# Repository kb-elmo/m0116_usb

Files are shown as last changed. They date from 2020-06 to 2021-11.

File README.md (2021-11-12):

# m0116_usb
[][cc-by-nc-sa]<a href="https://ko-fi.com/kb_elmo">kofibadge</a>

## This project is completed and will not get updated anymore.

### QMK compatible drop-in replacement PCB for the Apple M0116
The PCB is built entirely with THT parts to keep a somewhat "vintage" look to it and it uses the fullsize 40-pin DIP package ATmega32A.
The controller is placed in the exact same location as the one on the original PCB meaning that it can be accessed through the plate cutout under the spacebar.




### Partslist
 |Count|Part|
 |-|-|
 |1|ATmega32A 40 pin DIP (32L works too)|
 |1|40 pin DIP socket (optional but highly recommended)|
 |1|2x3 pin header 2.54mm (for ISP flashing)|
 |1|JST PH 2mm 4pin connector + cable|
 |1|mini usb port|
 |1|500 mA polyfuse|
 |2|6mm momentary push buttons|
 |1|16 MHz quarz crystal|
 |1|4.7 uF electrolytic capacitor|
 |2|100 nF ceramic disk capacitor|
 |2|22 pF ceramic disk capacitor|
 |1|10 kΩ resistor|
 |2|68 Ω resistor|
 |1|1.5 kΩ resistor|
 |2|3.6 V zener diode (DO-35 BZX55C3V6)|
 |81|universal switching diode (DO-35 1N4148)|

#### Some pictures of the first finished PCB
(https://i.imgur.com/0l0W3oY.jpg) (https://i.imgur.com/iAKeK4c.jpg)
(https://i.imgur.com/Zk1t3iO.jpg) (https://i.imgur.com/qjwVC6q.jpg)
(https://i.imgur.com/mmxlIqL.jpg) (https://i.imgur.com/rhK3iEW.jpg)

This work is licensed under a
[Creative Commons Attribution-NonCommercial-ShareAlike 4.0 International License][cc-by-nc-sa].

[][cc-by-nc-sa]

[cc-by-nc-sa]: http://creativecommons.org/licenses/by-nc-sa/4.0/
[cc-by-nc-sa-image]: https://licensebuttons.net/l/by-nc-sa/4.0/88x31.png
[cc-by-nc-sa-shield]: https://img.shields.io/badge/License-CC%20BY--NC--SA%204.0-lightgrey.svg

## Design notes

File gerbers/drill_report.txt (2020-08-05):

Drill report for m0116_usb.kicad_pcb
Created on Wed Aug  5 12:54:41 2020

Copper Layer Stackup:
    =============================================================
    L1 :  F.Cu                      front
    L2 :  B.Cu                      back

Drill file 'm0116_usb.drl' contains
    plated through holes:
    =============================================================
    T1  0.40mm  0.016"  (4 holes)
    T2  0.70mm  0.028"  (7 holes)  (with 7 slots)
    T3  0.75mm  0.030"  (4 holes)
    T4  0.80mm  0.031"  (230 holes)
    T5  1.00mm  0.039"  (8 holes)
    T6  1.10mm  0.043"  (8 holes)
    T7  1.47mm  0.058"  (162 holes)

    Total plated holes count 423

Not plated through holes are merged with plated holes
    unplated through holes:
    =============================================================

    Total unplated holes count 0

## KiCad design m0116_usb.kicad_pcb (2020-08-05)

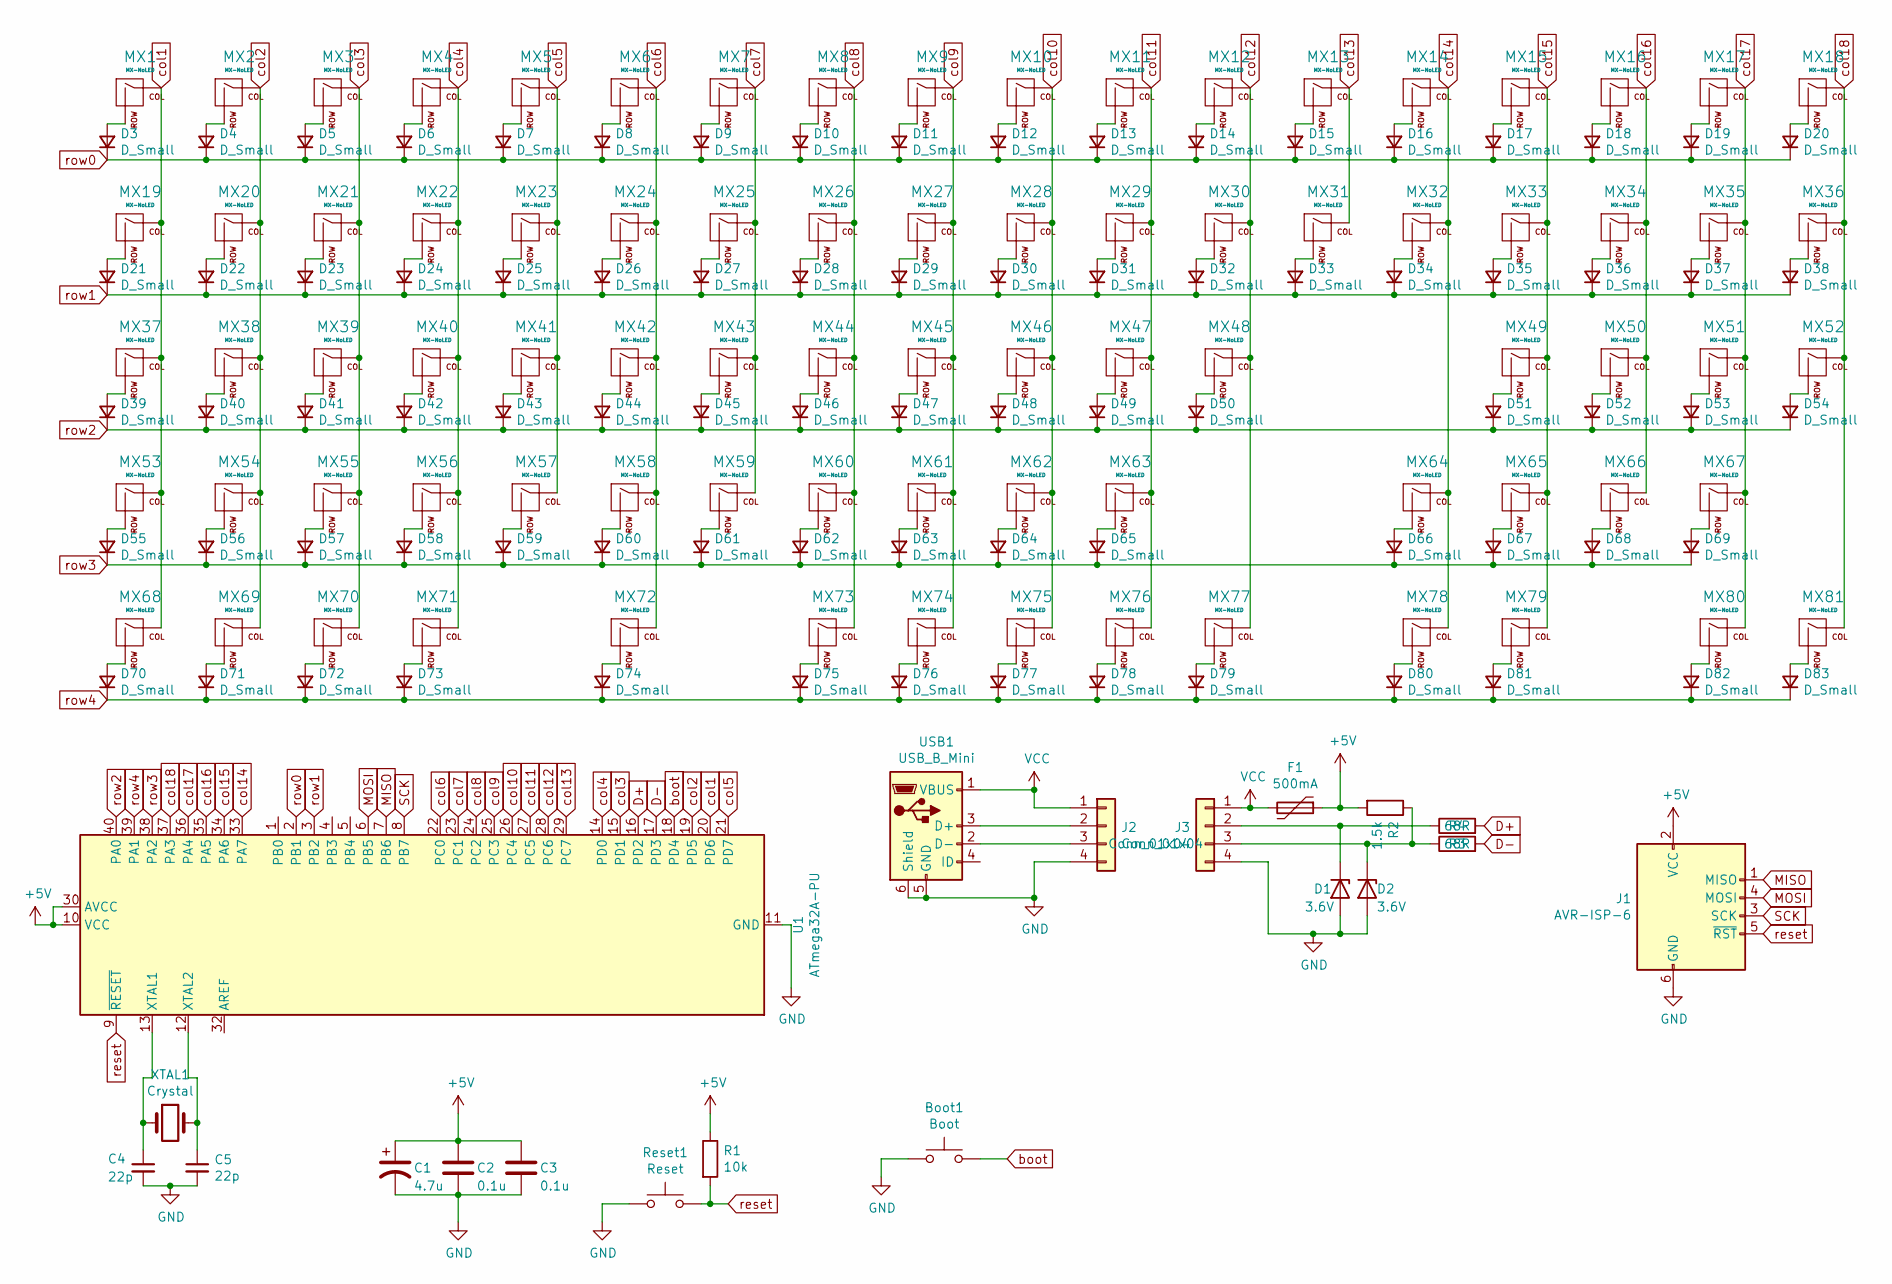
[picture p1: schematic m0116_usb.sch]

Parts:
Boot1: Boot; SW_PUSH_6mm
C1: 4.7u; CP_Radial_D5.0mm_P2.50mm
C2, C3: 0.1u; C_Disc_D3.0mm_W2.0mm_P2.50mm
C4, C5: 22p; C_Disc_D6.0mm_W2.5mm_P5.00mm
D1, D2: 3.6V; D_DO-35_SOD27_P7.62mm_Horizontal
D3, D4, D5, D6, D7, D8, D9, D10, D11, D12, D13, D14, D15, D16, D17, D18, D19, D20, D21, D22, D23, D24, D25, D26, D27, D28, D29, D30, D31, D32, D33, D34, D35, D36, D37, D38, D39, D40, D41, D42, D43, D44, D45, D46, D47, D48, D49, D50, D51, D52, D53, D54, D55, D56, D57, D58, D59, D60, D61, D62, D63, D64, D65, D66, D67, D68, D69, D70, D71, D72, D73, D74, D75, D76, D77, D78, D79, D80, D81, D82, D83: D_Small; D_DO-35_SOD27_P7.62mm_Horizontal
F1: 500mA; Fuse_Littelfuse_395Series
J1: AVR-ISP-6; PinHeader_2x03_P2.54mm_Horizontal
J2: Conn_01x04; PinHeader_1x04_P2.00mm_Vertical
J3: Conn_01x04; JST_PH_S4B-PH-K_1x04_P2.00mm_Horizontal
MX1, MX2, MX3, MX4, MX5, MX6, MX7, MX8, MX9, MX10, MX11, MX12, MX13, MX14, MX15, MX16, MX17, MX18, MX19, MX20, MX21, MX22, MX23, MX24, MX25, MX26, MX27, MX28, MX29, MX30, MX31, MX32, MX33, MX34, MX35, MX36, MX37, MX38, MX39, MX40, MX41, MX42, MX43, MX44, MX45, MX46, MX47, MX48, MX49, MX50, MX51, MX52, MX53, MX54, MX55, MX56, MX57, MX58, MX59, MX60, MX61, MX62, MX63, MX64, MX65, MX66, MX67, MX68, MX69, MX70, MX71, MX72, MX73, MX74, MX75, MX76, MX77, MX78, MX79, MX80, MX81: MX-NoLED; ALPS-1U
R1: 10k; R_Axial_DIN0207_L6.3mm_D2.5mm_P10.16mm_Horizontal
R2: 1.5k; R_Axial_DIN0207_L6.3mm_D2.5mm_P10.16mm_Horizontal
R3, R4: 68R; R_Axial_DIN0207_L6.3mm_D2.5mm_P10.16mm_Horizontal
Reset1: Reset; SW_PUSH_6mm
U1: ATmega32A-PU; DIP-40_W15.24mm_Socket
USB1: USB_B_Mini; Molex-0548190519
XTAL1: Crystal; Crystal_HC49-4H_Vertical

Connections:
+5V: C1.1, C2.1, C3.1, F1.1, J1.2 (VCC), R1.1, R2.2, U1.10 (VCC), U1.30 (AVCC)
D+: R3.2, U1.16 (PD2)
D-: R4.2, U1.17 (PD3)
GND: Boot1.1, C1.2, C2.2, C3.2, C4.2, C5.2, D1.2 (A), D2.2 (A), J1.6 (GND), J2.4, J3.4, Reset1.1, U1.11 (GND), U1.31 (GND), USB1.5 (GND), USB1.6 (Shield); also elsewhere on the board
MISO: J1.1 (MISO), U1.7 (PB6)
MOSI: J1.4 (MOSI), U1.6 (PB5)
unnamed: C4.1, U1.13 (XTAL1), XTAL1.1
unnamed: C5.1, U1.12 (XTAL2), XTAL1.2
unnamed: D1.1 (K), J3.2, R3.1
unnamed: D2.1 (K), J3.3, R2.1, R4.1
unnamed: D3.2 (A), MX1.2 (ROW)
unnamed: D4.2 (A), MX2.2 (ROW)
unnamed: D5.2 (A), MX3.2 (ROW)
unnamed: D6.2 (A), MX4.2 (ROW)
unnamed: D7.2 (A), MX5.2 (ROW)
unnamed: D8.2 (A), MX6.2 (ROW)
unnamed: D9.2 (A), MX7.2 (ROW)
unnamed: D10.2 (A), MX8.2 (ROW)
unnamed: D11.2 (A), MX9.2 (ROW)
unnamed: D12.2 (A), MX10.2 (ROW)
unnamed: D13.2 (A), MX11.2 (ROW)
unnamed: D14.2 (A), MX12.2 (ROW)
unnamed: D15.2 (A), MX13.2 (ROW)
unnamed: D16.2 (A), MX14.2 (ROW)
unnamed: D17.2 (A), MX15.2 (ROW)
unnamed: D18.2 (A), MX16.2 (ROW)
unnamed: D19.2 (A), MX17.2 (ROW)
unnamed: D20.2 (A), MX18.2 (ROW)
unnamed: D21.2 (A), MX19.2 (ROW)
unnamed: D22.2 (A), MX20.2 (ROW)
unnamed: D23.2 (A), MX21.2 (ROW)
unnamed: D24.2 (A), MX22.2 (ROW)
unnamed: D25.2 (A), MX23.2 (ROW)
unnamed: D26.2 (A), MX24.2 (ROW)
unnamed: D27.2 (A), MX25.2 (ROW)
unnamed: D28.2 (A), MX26.2 (ROW)
unnamed: D29.2 (A), MX27.2 (ROW)
unnamed: D30.2 (A), MX28.2 (ROW)
unnamed: D31.2 (A), MX29.2 (ROW)
unnamed: D32.2 (A), MX30.2 (ROW)
unnamed: D33.2 (A), MX31.2 (ROW)
unnamed: D34.2 (A), MX32.2 (ROW)
unnamed: D35.2 (A), MX33.2 (ROW)
unnamed: D36.2 (A), MX34.2 (ROW)
unnamed: D37.2 (A), MX35.2 (ROW)
unnamed: D38.2 (A), MX36.2 (ROW)
unnamed: D39.2 (A), MX37.2 (ROW)
unnamed: D40.2 (A), MX38.2 (ROW)
unnamed: D41.2 (A), MX39.2 (ROW)
unnamed: D42.2 (A), MX40.2 (ROW)
unnamed: D43.2 (A), MX41.2 (ROW)
unnamed: D44.2 (A), MX42.2 (ROW)
unnamed: D45.2 (A), MX43.2 (ROW)
unnamed: D46.2 (A), MX44.2 (ROW)
unnamed: D47.2 (A), MX45.2 (ROW)
unnamed: D48.2 (A), MX46.2 (ROW)
unnamed: D49.2 (A), MX47.2 (ROW)
unnamed: D50.2 (A), MX48.2 (ROW)
unnamed: D51.2 (A), MX49.2 (ROW)
unnamed: D52.2 (A), MX50.2 (ROW)
unnamed: D53.2 (A), MX51.2 (ROW)
unnamed: D54.2 (A), MX52.2 (ROW)
unnamed: D55.2 (A), MX53.2 (ROW)
unnamed: D56.2 (A), MX54.2 (ROW)
unnamed: D57.2 (A), MX55.2 (ROW)
unnamed: D58.2 (A), MX56.2 (ROW)
unnamed: D59.2 (A), MX57.2 (ROW)
unnamed: D60.2 (A), MX58.2 (ROW)
unnamed: D61.2 (A), MX59.2 (ROW)
unnamed: D62.2 (A), MX60.2 (ROW)
unnamed: D63.2 (A), MX61.2 (ROW)
unnamed: D64.2 (A), MX62.2 (ROW)
unnamed: D65.2 (A), MX63.2 (ROW)
unnamed: D66.2 (A), MX64.2 (ROW)
unnamed: D67.2 (A), MX65.2 (ROW)
unnamed: D68.2 (A), MX66.2 (ROW)
unnamed: D69.2 (A), MX67.2 (ROW)
unnamed: D70.2 (A), MX68.2 (ROW)
unnamed: D71.2 (A), MX69.2 (ROW)
unnamed: D72.2 (A), MX70.2 (ROW)
unnamed: D73.2 (A), MX71.2 (ROW)
unnamed: D74.2 (A), MX72.2 (ROW)
unnamed: D75.2 (A), MX73.2 (ROW)
unnamed: D76.2 (A), MX74.2 (ROW)
unnamed: D77.2 (A), MX75.2 (ROW)
unnamed: D78.2 (A), MX76.2 (ROW)
unnamed: D79.2 (A), MX77.2 (ROW)
unnamed: D80.2 (A), MX78.2 (ROW)
unnamed: D81.2 (A), MX79.2 (ROW)
unnamed: D82.2 (A), MX80.2 (ROW)
unnamed: D83.2 (A), MX81.2 (ROW)
unnamed: J2.2, USB1.3 (D+)
unnamed: J2.3, USB1.2 (D-)
SCK: J1.3 (SCK), U1.8 (PB7)
VCC: F1.2, J2.1, J3.1, USB1.1 (VBUS)
boot: Boot1.2, U1.18 (PD4); also elsewhere on the board
col1: MX1.1 (COL), MX19.1 (COL), MX37.1 (COL), MX53.1 (COL), MX68.1 (COL), U1.20 (PD6)
col2: MX2.1 (COL), MX20.1 (COL), MX38.1 (COL), MX54.1 (COL), MX69.1 (COL), U1.19 (PD5)
col3: MX3.1 (COL), MX21.1 (COL), MX39.1 (COL), MX55.1 (COL), MX70.1 (COL), U1.15 (PD1)
col4: MX4.1 (COL), MX22.1 (COL), MX40.1 (COL), MX56.1 (COL), MX71.1 (COL), U1.14 (PD0)
col5: MX5.1 (COL), MX23.1 (COL), MX41.1 (COL), MX57.1 (COL), U1.21 (PD7)
col6: MX6.1 (COL), MX24.1 (COL), MX42.1 (COL), MX58.1 (COL), MX72.1 (COL), U1.22 (PC0)
col7: MX7.1 (COL), MX25.1 (COL), MX43.1 (COL), MX59.1 (COL), U1.23 (PC1)
col8: MX8.1 (COL), MX26.1 (COL), MX44.1 (COL), MX60.1 (COL), MX73.1 (COL), U1.24 (PC2)
col9: MX9.1 (COL), MX27.1 (COL), MX45.1 (COL), MX61.1 (COL), MX74.1 (COL), U1.25 (PC3)
col10: MX10.1 (COL), MX28.1 (COL), MX46.1 (COL), MX62.1 (COL), MX75.1 (COL), U1.26 (PC4)
col11: MX11.1 (COL), MX29.1 (COL), MX47.1 (COL), MX63.1 (COL), MX76.1 (COL), U1.27 (PC5)
col12: MX12.1 (COL), MX30.1 (COL), MX48.1 (COL), MX77.1 (COL), U1.28 (PC6)
col13: MX13.1 (COL), MX31.1 (COL), U1.29 (PC7)
col14: MX14.1 (COL), MX32.1 (COL), MX64.1 (COL), MX78.1 (COL), U1.33 (PA7)
col15: MX15.1 (COL), MX33.1 (COL), MX49.1 (COL), MX65.1 (COL), MX79.1 (COL), U1.34 (PA6)
col16: MX16.1 (COL), MX34.1 (COL), MX50.1 (COL), MX66.1 (COL), U1.35 (PA5)
col17: MX17.1 (COL), MX35.1 (COL), MX51.1 (COL), MX67.1 (COL), MX80.1 (COL), U1.36 (PA4)
col18: MX18.1 (COL), MX36.1 (COL), MX52.1 (COL), MX81.1 (COL), U1.37 (PA3)
reset: J1.5 (~RST), R1.2, Reset1.2, U1.9 (~RESET); also elsewhere on the board
row0: D3.1 (K), D4.1 (K), D5.1 (K), D6.1 (K), D7.1 (K), D8.1 (K), D9.1 (K), D10.1 (K), D11.1 (K), D12.1 (K), D13.1 (K), D14.1 (K), D15.1 (K), D16.1 (K), D17.1 (K), D18.1 (K), D19.1 (K), D20.1 (K), U1.2 (PB1)
row1: D21.1 (K), D22.1 (K), D23.1 (K), D24.1 (K), D25.1 (K), D26.1 (K), D27.1 (K), D28.1 (K), D29.1 (K), D30.1 (K), D31.1 (K), D32.1 (K), D33.1 (K), D34.1 (K), D35.1 (K), D36.1 (K), D37.1 (K), D38.1 (K), U1.3 (PB2)
row2: D39.1 (K), D40.1 (K), D41.1 (K), D42.1 (K), D43.1 (K), D44.1 (K), D45.1 (K), D46.1 (K), D47.1 (K), D48.1 (K), D49.1 (K), D50.1 (K), D51.1 (K), D52.1 (K), D53.1 (K), D54.1 (K), U1.40 (PA0)
row3: D55.1 (K), D56.1 (K), D57.1 (K), D58.1 (K), D59.1 (K), D60.1 (K), D61.1 (K), D62.1 (K), D63.1 (K), D64.1 (K), D65.1 (K), D66.1 (K), D67.1 (K), D68.1 (K), D69.1 (K), U1.38 (PA2)
row4: D70.1 (K), D71.1 (K), D72.1 (K), D73.1 (K), D74.1 (K), D75.1 (K), D76.1 (K), D77.1 (K), D78.1 (K), D79.1 (K), D80.1 (K), D81.1 (K), D82.1 (K), D83.1 (K), U1.39 (PA1)

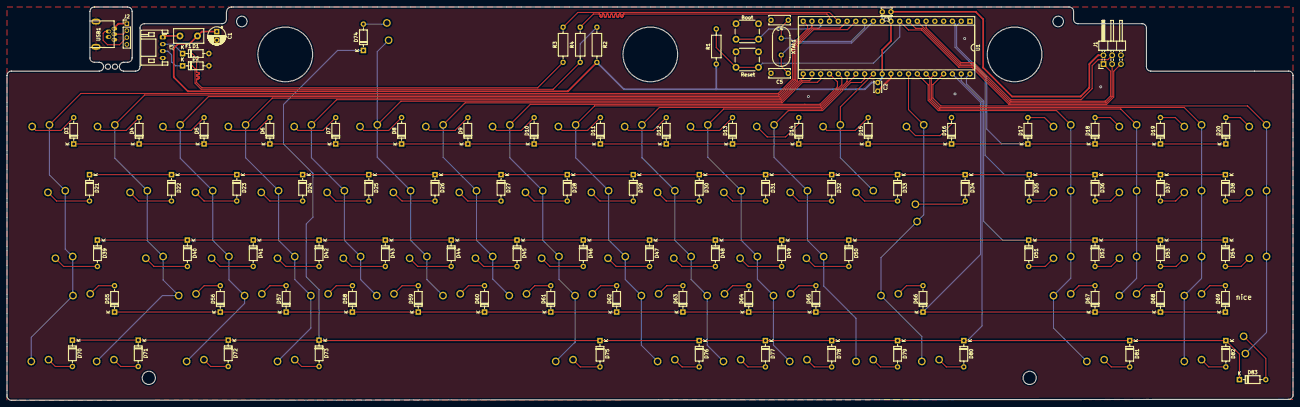
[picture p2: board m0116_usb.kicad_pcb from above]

Board: 2 copper layers, 372.1 x 113.8 mm, 182 parts (0 on the bottom side), 120 nets.

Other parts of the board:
Boot: Boot; SW_PUSH_6mm
Reset: Reset; SW_PUSH_6mm

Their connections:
GND: Boot.1, Reset.1; also elsewhere on the board
boot: Boot.2; also elsewhere on the board
reset: Reset.2; also elsewhere on the board

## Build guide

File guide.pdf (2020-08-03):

## Apple M0116 USB PCB build guide

Very quick and dirty build guide.
If you need further help DM me on Reddit (u/_vastrox_) or on Discord (elmo#0101).

Parts required:
1 | ATmega32A 40 pin DIP (32L works too)
1 | 40 pin DIP socket (optional but highly recommended)
1 | 2x3 pin header 2.54mm (for ISP flashing)
1 | JST HA 2mm connector + cable (included in the package)
1 | Mini USB port (included in the package)
1 | 500 mA polyfuse
2 | 6mm momentary push buttons
1 | 16 MHz quarz crystal
1 | 4.7 uF electrolytic capacitor
2 | 100 nF ceramic disk capacitor
2 | 22 pF ceramic disk capacitor
1 | 10 kΩ resistor
2 | 68 Ω resistor
1 | 1.5 kΩ resistor
2 | 3.6 V zener diode (DO-35 BZX55C3V6)
81 | universal switching diode (DO-35 1N4148)

All of these parts can be easily found on eBay for fairly cheap prices.

Building the PCB:

1. Start with the controller socket. Put it in with the cutout nose like it‘s shown on the PCB silkscreen. Hold it in place with some electrical tape on top of the board. Solder every second pin on the board to prevent overheating the plastic. Then do the rest of the pins.
2. Solder in the quarz crystal into it‘s spot next to the controller (XTAL1). Polarity doesn‘t matter here. Do not pull hard on the parts legs as they can rip out quite easy.

### 3. Solder in the capacitors. The values are as follows:

- C1 (ELKO! Watch the polarity! white side = negative) = 4.7uF
- C2 & C3 (next to the controller socket) = 100nF
- C4 & C5 (left and right of the crystal) = 22pF

### 4. Next up are the two 3.6V Zener diodes. They go into the spots D1 and D2. Watch the

polarity! The white line on the silkscreen has to match with the black or white line on the diode.

### 5. Now come the resistors. Their values are as follows:

- R1 (next to the reset button) = 10kΩ
- R2 = 1.5kΩ
- R3 & R4 = 68Ω

### 6. Solder in the rest of the parts:

- the 500mA polyfuse (spot F1)
- LED (watch the polarity, square pad = negative)
- JST connector (goes on the bottom side of the board facing down like the silkscreen shows)
- the boot pushbutton (do not solder in the reset button as it won‘t fit under the plate. just clip it into place so that you can remove it later)
- ISP flash connector (2x3 pin header) soldered in on top of the boards pointing towards you)
7. Finish the board by soldering in all 81 diodes. Watch the polarity (white stripe)

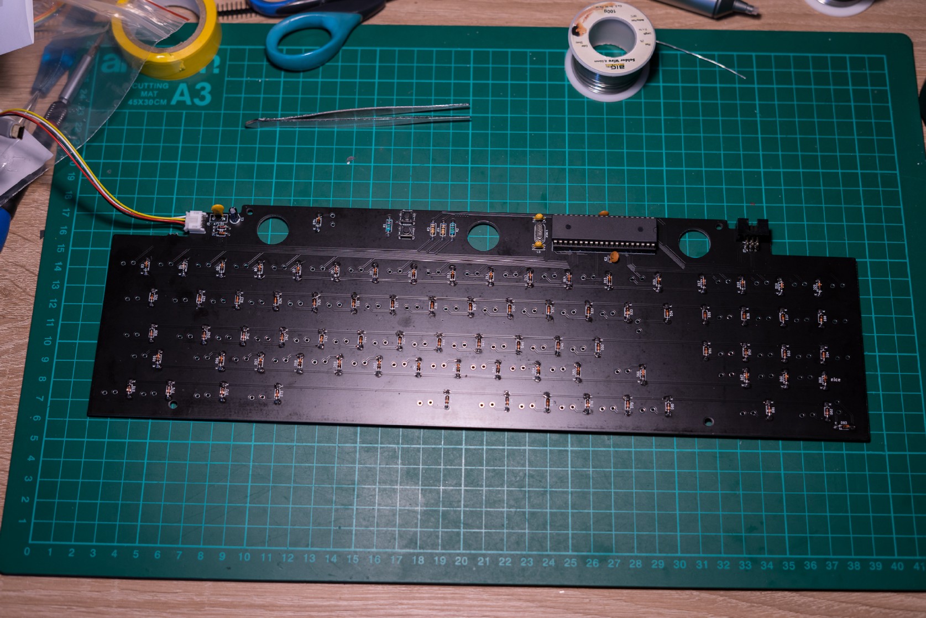
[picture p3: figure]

Building and flashing the bootloader:

Download the bootloader firmware from here: https://github.com/kb-elmo/m0116_usb/tree/master/firmware/bootloader

You need either a Linux system or MingW on Windows for this as this requires compiling some stuff.

The firmware is already set up and you don‘t need to change anything in the configuration files for this board.

### 1. Build the bootloader firmware by running „make“ on your console

### 2. Make sure that you can reach the controller by executing a chip erase with

„avrude -c usbasp -p m32 -e“ (you have to run these commands as root in Linux)

### 3. Flash the firmware on the controller with „make flash“

### 4. Set the controller fuses to the correct values „make fuse“

### 5. Finally lock the controller bootloader in place with „make lock“

The avrdude tool should show a „success“ after each operation. If the flashing process was successful you can unplug the ASP flasher and plug in the USB now.

Building and flashing QMK:

Unfortunately the pull request to integrate the board into the official QMK repository has still not been approved so you will have to clone and build QMK locally on your machine. To set up the build environment simply follow the guide on https://docs.qmk.fm

After you have set up your QMK environment copy and paste the files from https://github.com/kb-elmo/m0116_usb/tree/master/firmware/qmk
into a new folder called m0116_usb inside the keyboards folder of QMK.

Edit the keymap.c file in the default keymap to your liking and then build and flash the firmware with (set the board into bootloader mode first by holding down the boot button and tapping the reset button once): „make m0116_usb:default:usbasp“

QMK should now flash the board automatically. After the flashing was successful press the reset button once to reset the board. The PCB should now work as a keyboard.

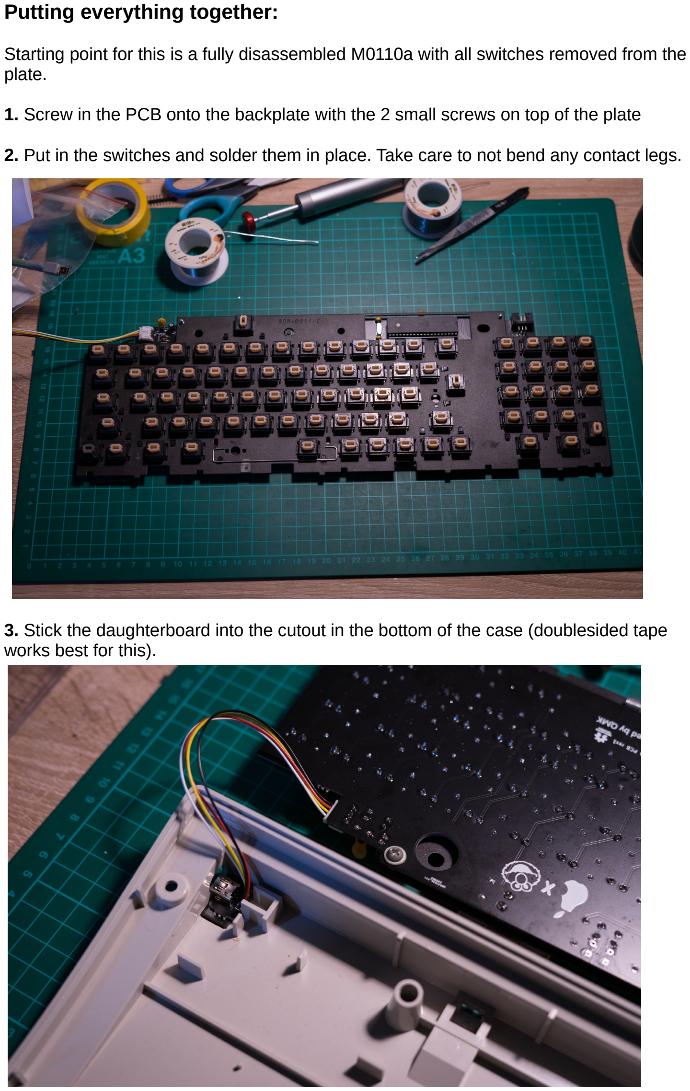
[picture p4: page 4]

Putting everything together:

Starting point for this is a fully disassembled M0110a with all switches removed from the plate.

### 1. Screw in the PCB onto the backplate with the 2 small screws on top of the plate

2. Put in the switches and solder them in place. Take care to not bend any contact legs.

### 3. Stick the daughterboard into the cutout in the bottom of the case (doublesided tape

works best for this).

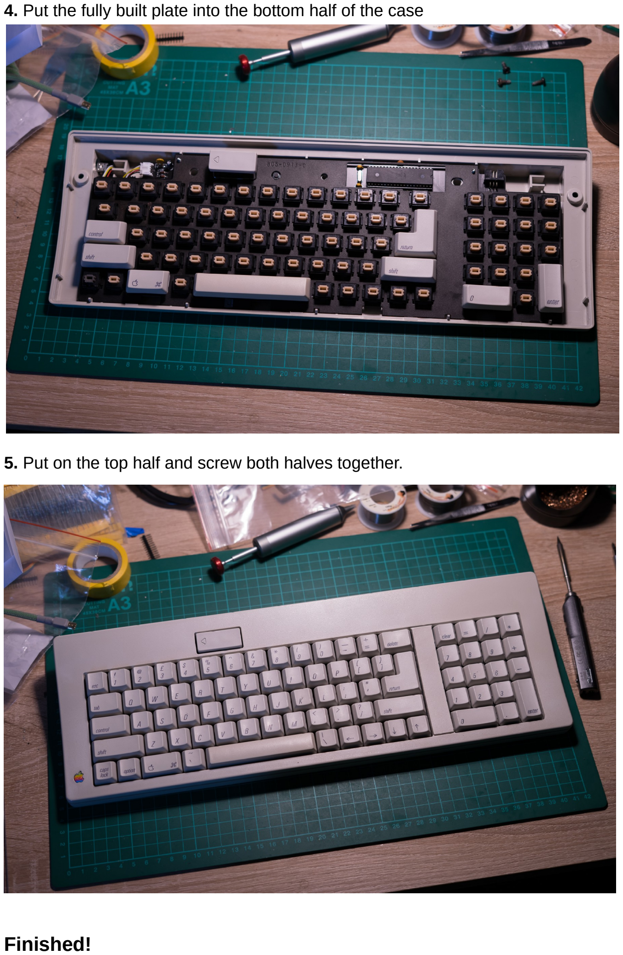
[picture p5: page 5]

### 4. Put the fully built plate into the bottom half of the case

5. Put on the top half and screw both halves together.

Finished!

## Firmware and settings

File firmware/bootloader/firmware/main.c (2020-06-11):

/* Name: main.c
 * Project: USBaspLoader
 * Author: Christian Starkjohann
 * Author: Stephan Baerwolf
 * Creation Date: 2007-12-08
 * Modification Date: 2013-03-31
 * Tabsize: 4
 * Copyright: (c) 2007 by OBJECTIVE DEVELOPMENT Software GmbH
 * License: GNU GPL v2 (see License.txt)
 */

#include "spminterface.h"  /* must be included as first! */

#include "../misc/iofixes.h"

#include <avr/interrupt.h>
#include <avr/pgmspace.h>
#include <avr/wdt.h>
#include <avr/boot.h>
#include <avr/eeprom.h>
#include <util/delay.h>


#if 0
/*
 * 29.09.2012 /  30.09.2012
 * 
 * Since cpufunc.h is not needed in this context and
 * since it is not available in all toolchains, this include
 * becomes deactivated by github issue-report.
 * (In case of trouble it remains in sourcecode for reactivation.)
 * 
 * The autor would like to thank Lena-M for reporting this
 * issue (https://github.com/baerwolf/USBaspLoader/issues/1).
 */
#include <avr/cpufunc.h>
#endif

#include <avr/boot.h>

#include <string.h>



#include "bootloaderconfig.h"

#include "usbdrv/usbdrv.c"
static usbMsgLen_t usbFunctionDescriptor(struct usbRequest *rq) {
  return 0;
}

#ifndef BOOTLOADER_ADDRESS
  #error need to know the bootloaders flash address!
#endif
#define BOOTLOADER_PAGEADDR	(BOOTLOADER_ADDRESS - (BOOTLOADER_ADDRESS % SPM_PAGESIZE))

/* ------------------------------------------------------------------------ */

/* Request constants used by USBasp */
#define USBASP_FUNC_CONNECT         1
#define USBASP_FUNC_DISCONNECT      2
#define USBASP_FUNC_TRANSMIT        3
#define USBASP_FUNC_READFLASH       4
#define USBASP_FUNC_ENABLEPROG      5
#define USBASP_FUNC_WRITEFLASH      6
#define USBASP_FUNC_READEEPROM      7
#define USBASP_FUNC_WRITEEEPROM     8
#define USBASP_FUNC_SETLONGADDRESS  9

// additional USBasp Commands
#define USBASP_FUNC_SETISPSCK	     10
#define USBASP_FUNC_TPI_CONNECT      11
#define USBASP_FUNC_TPI_DISCONNECT   12
#define USBASP_FUNC_TPI_RAWREAD      13
#define USBASP_FUNC_TPI_RAWWRITE     14
#define USBASP_FUNC_TPI_READBLOCK    15
#define USBASP_FUNC_TPI_WRITEBLOCK   16
#define USBASP_FUNC_GETCAPABILITIES 127
/* ------------------------------------------------------------------------ */

#ifndef ulong
#   define ulong    unsigned long
#endif
#ifndef uint
#   define uint     unsigned int
#endif


/* allow compatibility with avrusbboot's bootloaderconfig.h: */
#ifdef BOOTLOADER_INIT
#   define bootLoaderInit()         BOOTLOADER_INIT
#   define bootLoaderExit()
#endif
#ifdef BOOTLOADER_CONDITION
#   define bootLoaderCondition()    BOOTLOADER_CONDITION
#endif

/* device compatibility: */
#ifndef GICR    /* ATMega*8 don't have GICR, use MCUCR instead */
#   define GICR     MCUCR
#endif

/* ------------------------------------------------------------------------ */

#if (FLASHEND) > 0xffff /* we need long addressing */
#   define CURRENT_ADDRESS  currentAddress.l
#   define addr_t           ulong
#else
#   define CURRENT_ADDRESS  currentAddress.w[0]
#   define addr_t           uint
#endif

typedef union longConverter{
    addr_t  l;
    uint    w[sizeof(addr_t)/2];
    uchar   b[sizeof(addr_t)];
}longConverter_t;


#define __IMPLEMENT_PRESERVE_WATCHDOG	((PRESERVE_WATCHDOG) && (!(USE_EXCESSIVE_ASSEMBLER)) && ((NEED_WATCHDOG) || (defined(__MCUCSR_COMPATMODE))))
#if (__IMPLEMENT_PRESERVE_WATCHDOG)
static uint8_t __original_WDTCR;
#endif

#if (BOOTLOADER_CAN_EXIT)
#	if (BOOTLOADER_LOOPCYCLES_TIMEOUT)
#		if (BOOTLOADER_LOOPCYCLES_TIMEOUT < 256)
#			if ((HAVE_UNPRECISEWAIT))
	 register uint8_t timeout_remaining __asm__("r2");
#			else
static volatile uint8_t timeout_remaining;
#			endif
#		else
static volatile uint16_t timeout_remaining;
#		endif
#	endif

#	define stayinloader_initialValue 0xfe
#	if ((HAVE_UNPRECISEWAIT))
/* here we have to assume we need to optimize for every byte */
	 register uint8_t stayinloader __asm__("r17");
#	else
static volatile uint8_t stayinloader;
#	endif
#endif

static longConverter_t  	currentAddress; /* in bytes */
static uchar            	bytesRemaining;
static uchar            	isLastPage;
#if HAVE_EEPROM_PAGED_ACCESS
static uchar            	currentRequest;
#else
static const uchar      	currentRequest = 0;
#endif

static const uchar  signatureBytes[4] = {
#ifdef SIGNATURE_BYTES
    SIGNATURE_BYTES
#elif defined (__AVR_ATmega8535__)
    0x1e, 0x93, 0x08, 0
#elif defined (__AVR_ATmega8__) || defined (__AVR_ATmega8A__) || defined (__AVR_ATmega8HVA__)
    0x1e, 0x93, 0x07, 0
#elif defined (__AVR_ATmega16__)
    0x1e, 0x94, 0x03, 0
#elif defined (__AVR_ATmega32__)
    0x1e, 0x95, 0x02, 0
#elif defined (__AVR_ATmega48__) || defined (__AVR_ATmega48A__)
    #error ATmega48 does not support bootloaders!
    0x1e, 0x92, 0x05, 0
#elif defined (__AVR_ATmega48PA__) || defined (__AVR_ATmega48P__)
    #error ATmega48P does not support bootloaders!
    0x1e, 0x92, 0x0A, 0
#elif defined (__AVR_ATmega88__) || defined (__AVR_ATmega88A__)
    0x1e, 0x93, 0x0a, 0
#elif defined (__AVR_ATmega88PA__) || defined (__AVR_ATmega88P__)
    0x1e, 0x93, 0x0F, 0
#elif defined (__AVR_ATmega162__)
    0x1e, 0x94, 0x04, 0
#elif defined (__AVR_ATmega164A__)
    0x1e, 0x94, 0x0f, 0
#elif defined (__AVR_ATmega164P__) || defined (__AVR_ATmega164PA__)
    0x1e, 0x94, 0x0a, 0
#elif defined (__AVR_ATmega168__) || defined (__AVR_ATmega168A__)
    0x1e, 0x94, 0x06, 0
#elif defined (__AVR_ATmega168PA__) || defined (__AVR_ATmega168P__)
    0x1e, 0x94, 0x0B, 0
#elif defined (__AVR_ATmega324A__)
    0x1e, 0x95, 0x15, 0
#elif defined (__AVR_ATmega324P__)
    0x1e, 0x95, 0x08, 0
#elif defined (__AVR_ATmega324PA__)
    0x1e, 0x95, 0x11, 0
#elif defined (__AVR_ATmega328__)
    0x1e, 0x95, 0x14, 0
#elif defined (__AVR_ATmega328P__)
    0x1e, 0x95, 0x0f, 0
#elif defined (__AVR_ATmega640__)
    0x1e, 0x96, 0x08, 0
#elif defined (__AVR_ATmega644__) || defined (__AVR_ATmega644A__)
    0x1e, 0x96, 0x09, 0
#elif defined (__AVR_ATmega644P__) || defined (__AVR_ATmega644PA__)
    0x1e, 0x96, 0x0a, 0
#elif defined (__AVR_ATmega128__)
    0x1e, 0x97, 0x02, 0
#elif defined (__AVR_ATmega1280__)
    0x1e, 0x97, 0x03, 0
#elif defined (__AVR_ATmega1281__)
    0x1e, 0x97, 0x04, 0
#elif defined (__AVR_ATmega1284__)
    0x1e, 0x97, 0x06, 0
#elif defined (__AVR_ATmega1284P__)
    0x1e, 0x97, 0x05, 0
#elif defined (__AVR_ATmega2560__)
    0x1e, 0x98, 0x01, 0
#elif defined (__AVR_ATmega2561__)
    0x1e, 0x98, 0x02, 0
#else
#   if (defined(SIGNATURE_0) && defined(SIGNATURE_1) && defined(SIGNATURE_2))
#     warning "Device signature is not known - using AVR Libc suggestion..."
    SIGNATURE_0, SIGNATURE_1, SIGNATURE_2, 0
#   else
#     error "Device signature is not known, please edit main.c!"
#   endif
#endif
};

/* ------------------------------------------------------------------------ */

#if (HAVE_BOOTLOADERENTRY_FROMSOFTWARE)
void __attribute__ ((section(".init3"),naked,used,no_instrument_function)) __BOOTLOADERENTRY_FROMSOFTWARE__bootup_investigate_RAMEND(void);
void __BOOTLOADERENTRY_FROMSOFTWARE__bootup_investigate_RAMEND(void) {
  asm volatile (
    "in		%[mcucsrval]	,	%[mcucsrio]\n\t"
    "ldi	r29		,	%[ramendhi]\n\t"
    "ldi	r28		,	%[ramendlo]\n\t"
#if (FLASHEND>131071)
    "ld		%[result]	,	Y+\n\t"
    "cpi	%[result]	,	%[bootaddrhi]\n\t"
    "brne	__BOOTLOADERENTRY_FROMSOFTWARE__bootup_investigate_RAMEND_mismatch%=\n\t"
#endif
    "ld		%[result]	,	Y+\n\t"
    "cpi	%[result]	,	%[bootaddrme]\n\t"
    "ld		%[result]	,	Y+\n\t"
    "breq	__BOOTLOADERENTRY_FROMSOFTWARE__bootup_investigate_RAMEND_done%=\n\t"

    "__BOOTLOADERENTRY_FROMSOFTWARE__bootup_investigate_RAMEND_mismatch%=:\n\t"
    "ldi	%[result]	,	0xff\n\t"

    "__BOOTLOADERENTRY_FROMSOFTWARE__bootup_investigate_RAMEND_done%=:\n\t"
    : [result]		"=a" (__BOOTLOADERENTRY_FROMSOFTWARE__bootup_RAMEND_doesmatch),
      [mcucsrval]	"=a" (__BOOTLOADERENTRY_FROMSOFTWARE__bootup_MCUCSR)
    : [mcucsrio]	"I"  (_SFR_IO_ADDR(MCUCSR)),
#if (FLASHEND>131071)
      [ramendhi]	"M" (((RAMEND - 2) >> 8) & 0xff),
      [ramendlo]	"M" (((RAMEND - 2) >> 0) & 0xff),
      [bootaddrhi]	"M" (((__BOOTLOADERENTRY_FROMSOFTWARE__EXPECTEDADDRESS) >>16) & 0xff),
#else
      [ramendhi]	"M" (((RAMEND - 1) >> 8) & 0xff),
      [ramendlo]	"M" (((RAMEND - 1) >> 0) & 0xff),
#endif
      [bootaddrme]	"M" (((__BOOTLOADERENTRY_FROMSOFTWARE__EXPECTEDADDRESS) >> 8) & 0xff)
    
  );
}
#endif

#if (USE_BOOTUP_CLEARRAM)
/*
* Under normal circumstances, RESET will not clear contents of RAM.
* As always, if you want it done - do it yourself...
*/
void __attribute__ ((section(".init3"),naked,used,no_instrument_function)) __func_clearram(void);
void __func_clearram(void) {
  extern size_t __bss_end;
  asm volatile (
    "__clearram:\n\t"
#if (!(HAVE_BOOTLOADERENTRY_FROMSOFTWARE))
    "ldi r29, %[ramendhi]\n\t"
    "ldi r28, %[ramendlo]\n\t"
#endif
    "__clearramloop%=:\n\t"
    "st -Y , __zero_reg__\n\t"
    "cp r28, %A[bssend]\n\t"
    "cpc r29, %B[bssend]\n\t"
    "brne __clearramloop%=\n\t"
    :
    : [ramendhi] "M" (((RAMEND+1)>>8) & 0xff),
      [ramendlo] "M" (((RAMEND+1)>>0) & 0xff),
      [bssend] "r" (&__bss_end)
    : "memory"
      );
}
#endif

#if (!USE_EXCESSIVE_ASSEMBLER) || (!(defined (__AVR_ATmega8__) || defined (__AVR_ATmega8A__) || defined (__AVR_ATmega8HVA__)))
static void (*nullVector)(void) __attribute__((__noreturn__));
#endif

#if (USE_EXCESSIVE_ASSEMBLER) && (defined (__AVR_ATmega8__) || defined (__AVR_ATmega8A__) || defined (__AVR_ATmega8HVA__))
static void __attribute__((naked,__noreturn__)) leaveBootloader(void);
static void leaveBootloader(void) {
  asm  volatile  (
  "cli\n\t"
  "sbi		%[usbddr],	%[usbminus]\n\t"  
  "cbi		%[port],	%[bit]\n\t"
  "out		%[usbintrenab],	__zero_reg__\n\t"
  "out		%[usbintrcfg],	__zero_reg__\n\t"
  "ldi		r31,		%[ivce]\n\t"
  "out		%[mygicr],	r31\n\t"
  "out		%[mygicr],	__zero_reg__\n\t"  
  "rjmp		nullVector\n\t"
  :
  : [port]        "I" (_SFR_IO_ADDR(PIN_PORT(JUMPER_PORT))),
    [bit]         "I" (PIN(JUMPER_PORT, JUMPER_BIT)),
    [usbintrenab] "I" (_SFR_IO_ADDR(USB_INTR_ENABLE)),
    [usbintrcfg]  "I" (_SFR_IO_ADDR(USB_INTR_CFG)),
    [usbddr]      "I" (_SFR_IO_ADDR(USBDDR)),
    [usbminus]    "I" (USBMINUS),
    [mygicr]      "I" (_SFR_IO_ADDR(GICR)),	      
    [ivce]        "I" (1<<IVCE)
);
}
#else
static void __attribute__((__noreturn__)) leaveBootloader(void);
static void leaveBootloader(void) {
    DBG1(0x01, 0, 0);
    cli();
    usbDeviceDisconnect();
    bootLoaderExit();
    USB_INTR_ENABLE = 0;
    USB_INTR_CFG = 0;       /* also reset config bits */
    GICR = (1 << IVCE);     /* enable change of interrupt vectors */
    GICR = (0 << IVSEL);    /* move interrupts to application flash section */

/* restore the original watchdog timer if necessary */
#if (__IMPLEMENT_PRESERVE_WATCHDOG)
    if (__original_WDTCR & _BV(WDE)) {
      __original_WDTCR &= ~(_BV(WDCE));
      wdt_reset();
      WDTCR |= (_BV(WDCE)) | (_BV(WDE));
      WDTCR  = __original_WDTCR;
      wdt_reset();
    }
#endif
/*
 * There seems to be another funny compiler Bug.
 * When gcc is using "eicall" opcode it forgets to modify EIND.
 * On devices with large flash memory there are some target address bits
 * missing. In this case some zero bits...
 */
#if (defined(EIND) && ((FLASHEND)>131071))
  EIND=0;
#endif
/* We must go through a global function pointer variable instead of writing
 *  ((void (*)(void))0)();
 * because the compiler optimizes a constant 0 to "rcall 0" which is not
 * handled correctly by the assembler.
 */
    nullVector();
}
#endif

/* ------------------------------------------------------------------------ */


uchar usbFunctionSetup_USBASP_FUNC_TRANSMIT(usbRequest_t *rq) {
  uchar rval = 0;
  usbWord_t address;
  address.bytes[1] = rq->wValue.bytes[1];
  address.bytes[0] = rq->wIndex.bytes[0];

  if(rq->wValue.bytes[0] == 0x30){        /* read signature */
    rval = rq->wIndex.bytes[0] & 3;
    rval = signatureBytes[rval];
#if HAVE_READ_LOCK_FUSE
#if defined (__AVR_ATmega8535__) || 					\
    defined (__AVR_ATmega8__) || defined (__AVR_ATmega8A__) || 		\
    defined (__AVR_ATmega16__) || defined (__AVR_ATmega32__)
  }else if(rq->wValue.bytes[0] == 0x58 && rq->wValue.bytes[1] == 0x00){  /* read lock bits */
      rval = boot_lock_fuse_bits_get(GET_LOCK_BITS);
  }else if(rq->wValue.bytes[0] == 0x50 && rq->wValue.bytes[1] == 0x00){  /* read lfuse bits */
      rval = boot_lock_fuse_bits_get(GET_LOW_FUSE_BITS);
  }else if(rq->wValue.bytes[0] == 0x58 && rq->wValue.bytes[1] == 0x08){  /* read hfuse bits */
      rval = boot_lock_fuse_bits_get(GET_HIGH_FUSE_BITS);

#elif defined (__AVR_ATmega48__)   || defined (__AVR_ATmega48A__)   || defined (__AVR_ATmega48P__)   || defined (__AVR_ATmega48PA__)  ||  \
defined (__AVR_ATmega88__)   || defined (__AVR_ATmega88A__)   || defined (__AVR_ATmega88P__)   || defined (__AVR_ATmega88PA__)  ||  \
defined (__AVR_ATmega162__)  || 												      \
defined (__AVR_ATmega164A__) || defined (__AVR_ATmega164P__)  || 								      \
defined (__AVR_ATmega168__)  || defined (__AVR_ATmega168A__)  || defined (__AVR_ATmega168P__)  || defined (__AVR_ATmega168PA__) ||  \
defined (__AVR_ATmega324A__) || defined (__AVR_ATmega324P__)  ||								      \
defined (__AVR_ATmega328__)  || defined (__AVR_ATmega328P__)  ||								      \
defined (__AVR_ATmega640__)  ||													\
defined (__AVR_ATmega644__)  || defined (__AVR_ATmega644A__)  || defined (__AVR_ATmega644P__) || defined (__AVR_ATmega644PA__)  ||  \
defined (__AVR_ATmega128__)  ||													      \
defined (__AVR_ATmega1280__) ||													\
defined (__AVR_ATmega1281__) ||													\
defined (__AVR_ATmega1284__) || defined (__AVR_ATmega1284P__)  ||													\
defined (__AVR_ATmega2560__) ||													\
defined (__AVR_ATmega2561__)
  }else if(rq->wValue.bytes[0] == 0x58 && rq->wValue.bytes[1] == 0x00){  /* read lock bits */
      rval = boot_lock_fuse_bits_get(GET_LOCK_BITS);
  }else if(rq->wValue.bytes[0] == 0x50 && rq->wValue.bytes[1] == 0x00){  /* read lfuse bits */
      rval = boot_lock_fuse_bits_get(GET_LOW_FUSE_BITS);
  }else if(rq->wValue.bytes[0] == 0x58 && rq->wValue.bytes[1] == 0x08){  /* read hfuse bits */
      rval = boot_lock_fuse_bits_get(GET_HIGH_FUSE_BITS);
  }else if(rq->wValue.bytes[0] == 0x50 && rq->wValue.bytes[1] == 0x08){  /* read efuse bits */
      rval = boot_lock_fuse_bits_get(GET_EXTENDED_FUSE_BITS );
#else
  #warning "HAVE_READ_LOCK_FUSE is activated but MCU unknown -> will not support this feature"
#endif
#endif
#if HAVE_FLASH_BYTE_READACCESS
  }else if(rq->wValue.bytes[0] == 0x20){  /* read FLASH low  byte */
#if ((FLASHEND) > 65535)
      rval = pgm_read_byte_far((((addr_t)address.word)<<1)+0);
#else
      rval = pgm_read_byte((((addr_t)address.word)<<1)+0);
#endif
  }else if(rq->wValue.bytes[0] == 0x28){  /* read FLASH high byte */
#if ((FLASHEND) > 65535)
      rval = pgm_read_byte_far((((addr_t)address.word)<<1)+1);
#else
      rval = pgm_read_byte((((addr_t)address.word)<<1)+1);
#endif
#endif
#if HAVE_EEPROM_BYTE_ACCESS
  }else if(rq->wValue.bytes[0] == 0xa0){  /* read EEPROM byte */
      rval = eeprom_read_byte((void *)address.word);
  }else if(rq->wValue.bytes[0] == 0xc0){  /* write EEPROM byte */
      eeprom_write_byte((void *)address.word, rq->wIndex.bytes[1]);
#endif
#if HAVE_CHIP_ERASE
  }else if(rq->wValue.bytes[0] == 0xac && rq->wValue.bytes[1] == 0x80){  /* chip erase */
      addr_t addr;
#if HAVE_BLB11_SOFTW_LOCKBIT
      for(addr = 0; addr < (addr_t)(BOOTLOADER_PAGEADDR) ; addr += SPM_PAGESIZE) {
#else
      for(addr = 0; addr <= (addr_t)(FLASHEND) ; addr += SPM_PAGESIZE) {
#endif
	  /* wait and erase page */
	  DBG1(0x33, 0, 0);
#   ifndef NO_FLASH_WRITE
	  boot_spm_busy_wait();
	  cli();
	  boot_page_erase(addr);
	  sei();
#   endif
      }
#endif
#if ((HAVE_BOOTLOADER_HIDDENEXITCOMMAND) && (BOOTLOADER_CAN_EXIT))
#	if ((HAVE_BOOTLOADER_HIDDENEXITCOMMAND != 0xac) && \
	    (HAVE_BOOTLOADER_HIDDENEXITCOMMAND != 0x20) && (HAVE_BOOTLOADER_HIDDENEXITCOMMAND != 0x28) && \
	    (HAVE_BOOTLOADER_HIDDENEXITCOMMAND != 0x40) && (HAVE_BOOTLOADER_HIDDENEXITCOMMAND != 0x48) && \
	    (HAVE_BOOTLOADER_HIDDENEXITCOMMAND != 0x4c) && \
	    (HAVE_BOOTLOADER_HIDDENEXITCOMMAND != 0xa0) && \
	    (HAVE_BOOTLOADER_HIDDENEXITCOMMAND != 0xc0) && \
	    (HAVE_BOOTLOADER_HIDDENEXITCOMMAND != 0x58) && \
	    (HAVE_BOOTLOADER_HIDDENEXITCOMMAND != 0x5c) && \
	    (HAVE_BOOTLOADER_HIDDENEXITCOMMAND != 0x30) && \
	    (HAVE_BOOTLOADER_HIDDENEXITCOMMAND != 0xac) && \
	    (HAVE_BOOTLOADER_HIDDENEXITCOMMAND != 0x50) && (HAVE_BOOTLOADER_HIDDENEXITCOMMAND != 0x58) && \
	    (HAVE_BOOTLOADER_HIDDENEXITCOMMAND != 0x38))
  }else if(rq->wValue.bytes[0] == (HAVE_BOOTLOADER_HIDDENEXITCOMMAND)){  /* cause a bootLoaderExit at disconnect */
      stayinloader = 0xf1;  /* we need to be connected - so assume it */
#	endif
#endif
  }else{
      /* ignore all others, return default value == 0 */
  }
        
  return rval;
}


usbMsgLen_t usbFunctionSetup(uchar data[8])
{
usbRequest_t    *rq = (void *)data;
usbMsgLen_t     len = 0;
static uchar    replyBuffer[4];

    usbMsgPtr = (usbMsgPtr_t)replyBuffer;
    if(rq->bRequest == USBASP_FUNC_TRANSMIT){   /* emulate parts of ISP protocol */
        replyBuffer[3] = usbFunctionSetup_USBASP_FUNC_TRANSMIT(rq);
        len = (usbMsgLen_t)4;
    }else if((rq->bRequest == USBASP_FUNC_ENABLEPROG) || (rq->bRequest == USBASP_FUNC_SETISPSCK)){
        /* replyBuffer[0] = 0; is never touched and thus always 0 which means success */
        len = (usbMsgLen_t)1;
    }else if(rq->bRequest >= USBASP_FUNC_READFLASH && rq->bRequest <= USBASP_FUNC_SETLONGADDRESS){
        currentAddress.w[0] = rq->wValue.word;
        if(rq->bRequest == USBASP_FUNC_SETLONGADDRESS){
#if (FLASHEND) > 0xffff
            currentAddress.w[1] = rq->wIndex.word;
#endif
        }else{
            bytesRemaining = rq->wLength.bytes[0];
            /* if(rq->bRequest == USBASP_FUNC_WRITEFLASH) only evaluated during writeFlash anyway */
            isLastPage = rq->wIndex.bytes[1] & 0x02;
#if HAVE_EEPROM_PAGED_ACCESS
            currentRequest = rq->bRequest;
#endif
            len = USB_NO_MSG; /* hand over to usbFunctionRead() / usbFunctionWrite() */
        }

    }else if(rq->bRequest == USBASP_FUNC_DISCONNECT){

#if BOOTLOADER_CAN_EXIT
#	ifdef CONFIG_HAVE__BOOTLOADER_ABORTTIMEOUTONACT
      /* let the main loop know for ever that here was activity */
      stayinloader	   &= (0xfc);
#	else
      stayinloader	   &= (0xfe);
#	endif
#endif
    }else{
        /* ignore: others, but could be USBASP_FUNC_CONNECT */
#if BOOTLOADER_CAN_EXIT
	stayinloader	   |= (0x01);
#endif
    }
    return len;
}

#if (USE_EXCESSIVE_ASSEMBLER) && ((!HAVE_CHIP_ERASE) || (HAVE_ONDEMAND_PAGEERASE)) && (SPM_PAGESIZE <= 256) && (((BOOTLOADER_PAGEADDR>>0)&0xff) == 0)
uchar usbFunctionWrite(uchar *data, uchar len)
{
uchar   isLast;

    DBG1(0x31, (void *)&currentAddress.l, 4);
    if(len > bytesRemaining)
        len = bytesRemaining;
    bytesRemaining -= len;
    isLast = bytesRemaining == 0;
    if(currentRequest >= USBASP_FUNC_READEEPROM){
        uchar i;
        for(i = 0; i < len; i++){
            eeprom_write_byte((void *)(currentAddress.w[0]++), *data++);
        }
    }else{
	asm  volatile  (
	  "sbrc		%[len], 0\n\t"
	  "inc		%[len]\n\t"
"usbFunctionWrite_flashloop:\n\t"
	  "subi		%[len], 2\n\t"
	  "brlo		usbFunctionWrite_finished\n\t"
	  
#if HAVE_BLB11_SOFTW_LOCKBIT
	  "cpi		r31, %[blsaddrhi]\n\t"			/* accelerated BLB11_SOFTW_LOCKBIT check */
	  "brsh		usbFunctionWrite_finished\n\t"
// 	  "brlo		usbFunctionWrite_addrunlock_ok\n\t"
// 	  "brne		usbFunctionWrite_finished\n\t"
// 	  "cpi		r30, %[blsaddrlo]\n\t"
// 	  "brlo		usbFunctionWrite_addrunlock_ok\n\t"
// 	  "rjmp		usbFunctionWrite_finished\n\t"
// "usbFunctionWrite_addrunlock_ok:\n\t"
#endif
	  "rcall	usbFunctionWrite_waitA\n\t"
	  "cli\n\t"						/* r0 or r1 may be __zero_reg__ and may become dangerous nonzero within interrupts */
	  "ld		r0,		X+\n\t"
	  "ld		r1,		X+\n\t"

	  "ldi		r18,		%[pagfillval]\n\t"
	  "rcall	usbFunctionWrite_saveflash\n\t"	/* page fill */

	  "mov		r18,		r30\n\t"
	  "subi		r18,		0xfe\n\t"		/* add with 2 */
	  "andi		r18,		%[pagemask]\n\t"
	  "breq		usbFunctionWrite_pageisfull\n\t"
	  "tst		%[islast]\n\t"
	  "breq		usbFunctionWrite_skippageisfull\n\t"
	  "tst		%[isLastPage]\n\t"
	  "breq		usbFunctionWrite_skippageisfull\n\t"
	  "cpi		%[len],		0\n\t"
	  "brne		usbFunctionWrite_skippageisfull\n\t"

"usbFunctionWrite_pageisfull:\n\t"				/* start writing the page */
	  "ldi		r18,		%[pageraseval]\n\t"
	  "rcall	usbFunctionWrite_saveflash\n\t"	/* page erase */
	  "rcall	usbFunctionWrite_waitA\n\t"

	  "ldi		r18,		%[pagwriteval]\n\t"
	  "rcall	usbFunctionWrite_saveflash\n\t"	/* page write */
	  "rcall	usbFunctionWrite_waitA\n\t"

	  "in		__tmp_reg__,	%[spmcr]\n\t"
	  "sbrs		__tmp_reg__,	%[rwwsbbit]\n\t"
	  "rjmp		usbFunctionWrite_skippageisfull\n\t"
	  "ldi		r18,		%[rwwenrval]\n\t"
	  "rcall	usbFunctionWrite_saveflash\n\t"	/* reenable rww*/
// 	  "rcall	usbFunctionWrite_waitA\n\t"


"usbFunctionWrite_skippageisfull:\n\t"	  
	  "adiw		r30,		0x2\n\t"
	  "rjmp		usbFunctionWrite_flashloop\n\t"

"usbFunctionWrite_saveflash:\n\t"
	  "cli\n\t"
	  "out		%[spmcr],	r18\n\t"
	  "spm\n\t"
	  "clr		__zero_reg__\n\t"			/* if r0 or r1 is __zero_reg__ it may have become inconsisten while page-fill */
	  "sei\n\t"
	  "ret\n\t"

"usbFunctionWrite_waitA:\n\t"
	  "in		__tmp_reg__,	%[spmcr]\n\t"
	  "sbrc		__tmp_reg__,	%[spmenbit]\n\t"
	  "rjmp		usbFunctionWrite_waitA\n\t"
	  "ret\n\t"
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

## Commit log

2020-05-26 project start
    [m0116_usb.kicad_pcb, m0116_usb.sch]
2020-05-26 small fixes
    [m0116_usb.kicad_pcb]
2020-05-26 make JLC happy
    [m0116_usb-B_Cu.gbl, m0116_usb-B_Mask.gbs, m0116_usb-B_SilkS.gbo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]
2020-05-26 fix wrong resistor connection
    [m0116_usb-B_Cu.gbl, m0116_usb-B_Mask.gbs, m0116_usb-B_SilkS.gbo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]
2020-06-03 change design of daughterboard
    [m0116_usb.kicad_pcb, m0116_usb.sch]
2020-06-04 change JST connector size
    [m0116_usb-B_Cu.gbl, m0116_usb-B_Mask.gbs, m0116_usb-B_SilkS.gbo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]
2020-06-04 move the breakout pad to make JLC happy
    [m0116_usb-B_Cu.gbl, m0116_usb-B_Mask.gbs, m0116_usb-B_SilkS.gbo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]
2020-07-13 fixed clearance issues with buttons
    [m0116_usb-B_Cu.gbl, m0116_usb-B_Mask.gbs, m0116_usb-B_SilkS.gbo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]

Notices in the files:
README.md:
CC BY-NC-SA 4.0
